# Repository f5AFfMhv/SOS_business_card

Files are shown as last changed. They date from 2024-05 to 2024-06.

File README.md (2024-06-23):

# SOS Business Card PCB

This project was conceived for the [Hackaday 2024 Business Card Contest](https://hackaday.io/contest/195949-2024-business-card-contest). The idea was to create a logical circuit from discrete components that would generate a SOS signal in Morse code. I wanted to make this project a learning experience for creating logical circuits in a simple and practical way.

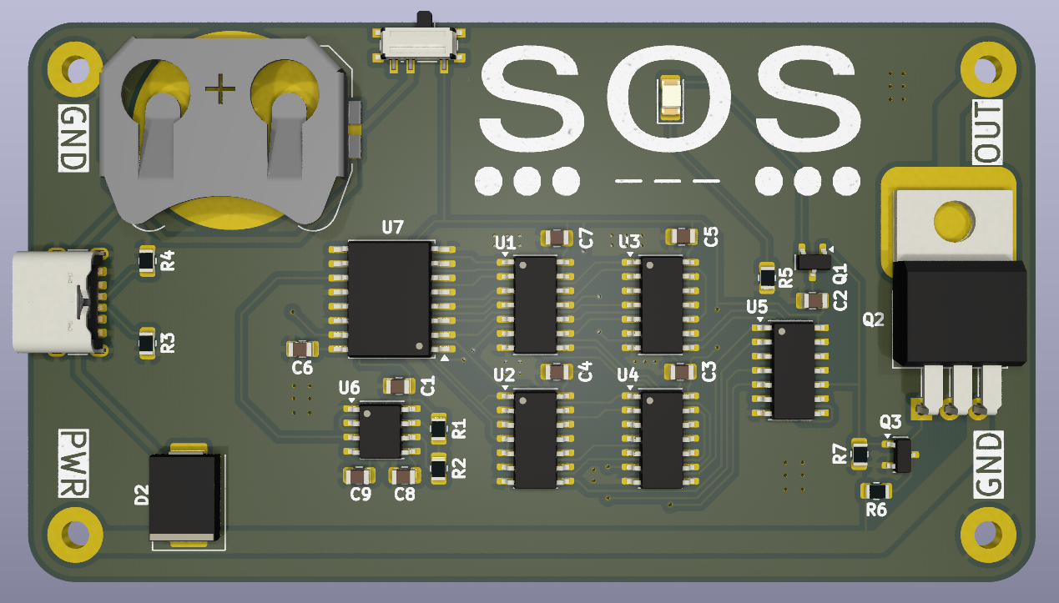
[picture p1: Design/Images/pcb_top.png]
pcb


## Logical Circuit Design

Morse code has following rules for signaling:

- dot is 1 time unit
- dash is 3 time units
- the space between symbols of the same letter is 1 time unit
- the space between words is 7 time units.

Following these rules SOS signal timing diagram will look like this:
wavedrome

> Diagram is made with [wavedrom online tool](https://wavedrom.com/editor.html). You can import json file from `Design/Wavedrom` for modifications.

We see that 34 independent logical states are needed. This introduces a problem as we could reduce logical circuit complexity by using 32 states instead as it will require 5 inputs for our truth table $(2^5=32)$.

I decided to violate last Morse code signaling rule and use 5 time units for spacing between words instead of 7.

I'm using [Logism](http://www.cburch.com/logisim/), it can take truth table as input and generate logical circuit. You can find Logism circuit files in `Design/Logism` directory. Generated circuit is not perfect and can be improved manually (by removing duplicated components and changing number of inputs for logical gates).

<div align="center">
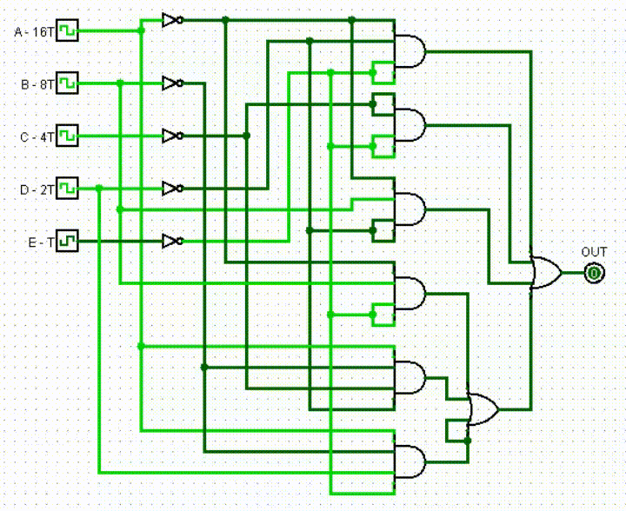
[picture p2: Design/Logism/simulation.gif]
logism
    
</div>

## Clock Circuit Design

For clock signal I'm using 555 timer. There are lots of tools online for calculating 555 timer circuit parameters. I used [555 Astable Circuit Calculator ](https://ohmslawcalculator.com/555-astable-calculator) for this.

General rules are:

- choose R2 value much higher than R1 for 50% duty cycle;
- C9 sets clock frequency. 330nF capacitor will generate 2Hz signal. To increase frequency, decrease C9 value.

<div align="center">
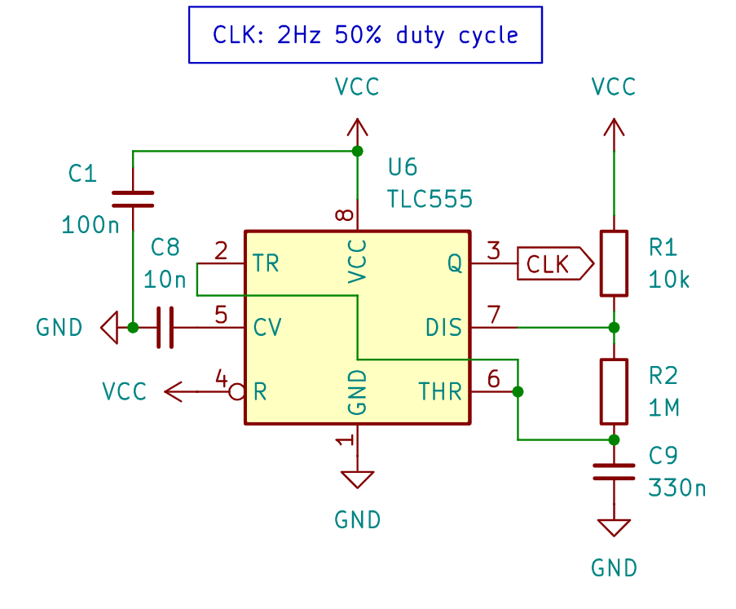
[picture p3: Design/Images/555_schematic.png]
    
</div>

For generating 5-bit logic circuit input signal we'll need binary counter. It will divide clock signal frequency by 2/4/8/16 and so on.

Full circuit simulation with 555 clock generator, binary counter and logical circuit was done using [Falstad](https://tinyurl.com/2bdrotlr). If link doesn't work, you can find Falstad circuit file in `Design/Falstad` directory.

## Power

Circuit will have 2 power options:

- CR2025 coin battery
- USB-C 5V@3A

USB-C socket CC lines are connected to ground via 5.1K ohm resistor. This tells power source to supply 5V on VBUS line. Most ICs I chose have maximum supply voltage of 6V.

## Output

The circuit will have a small on-board LED for SOS signal output. Additionally, a high-side PMOS load switch can be connected to a larger load, such as a 12V lamp. An external power supply with a maximum of 40V will be needed for this.

<div align="center">
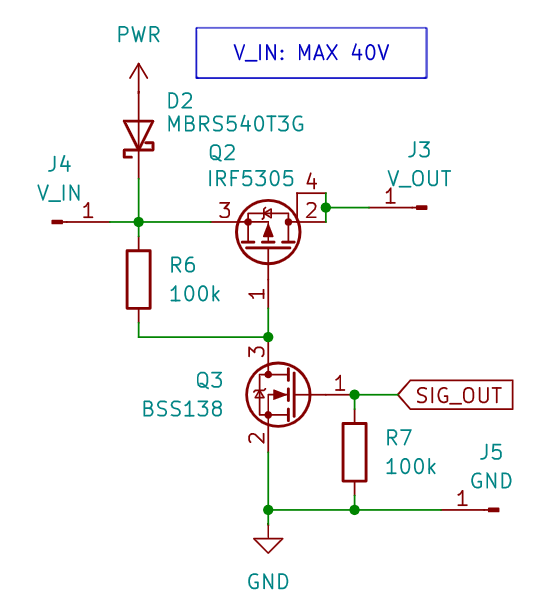
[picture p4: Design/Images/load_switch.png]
load switch
    
</div>

## PCB Design

PCB is designed using KiCAD. All project and gerber files are in `KiCAD` directory.
Full [schematic](schematic.pdf) exported as pdf.

There are some custom symbols and footprints used in this project. Those can be imported from [this](https://github.com/f5AFfMhv/my-kicad-libraries) github repository.

## Finished Project

<div align="center">
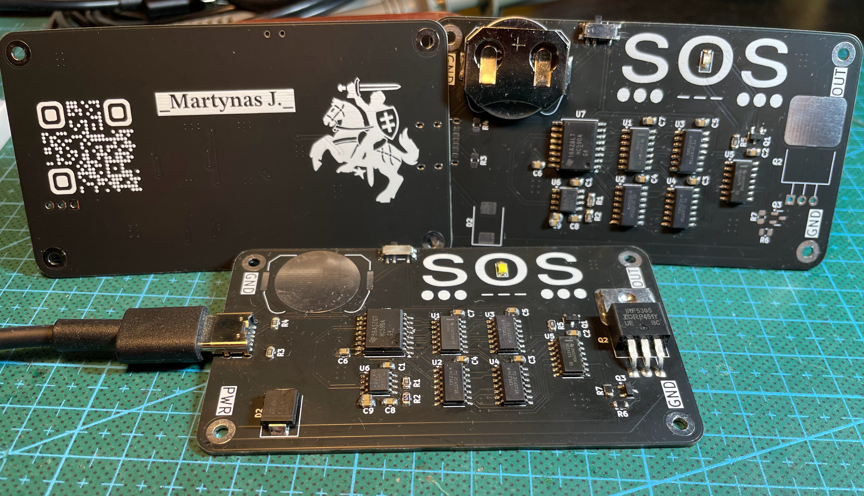
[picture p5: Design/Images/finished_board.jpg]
board
    
</div>

Youtube video.
[](https://www.youtube.com/embed/pKzfa068GOo)

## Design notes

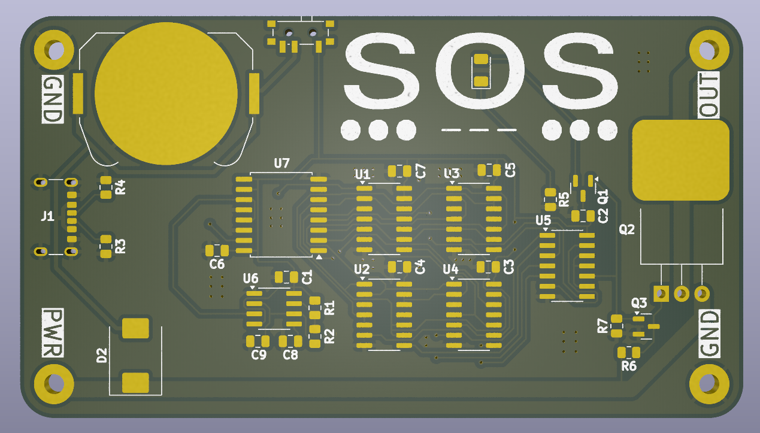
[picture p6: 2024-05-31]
Design/Images/bare_pcb_top.png

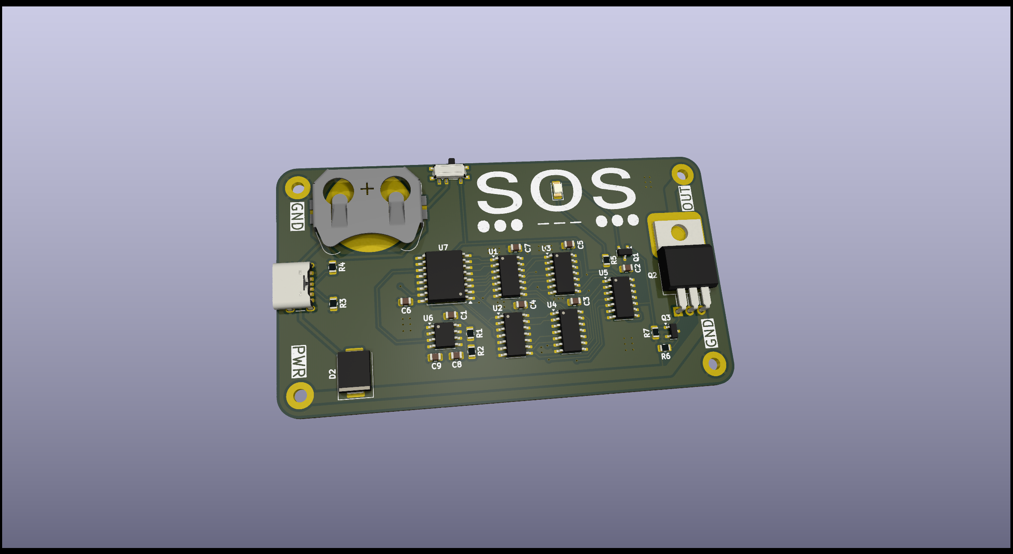
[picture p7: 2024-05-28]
Design/Images/pcb_3d_view_front.png

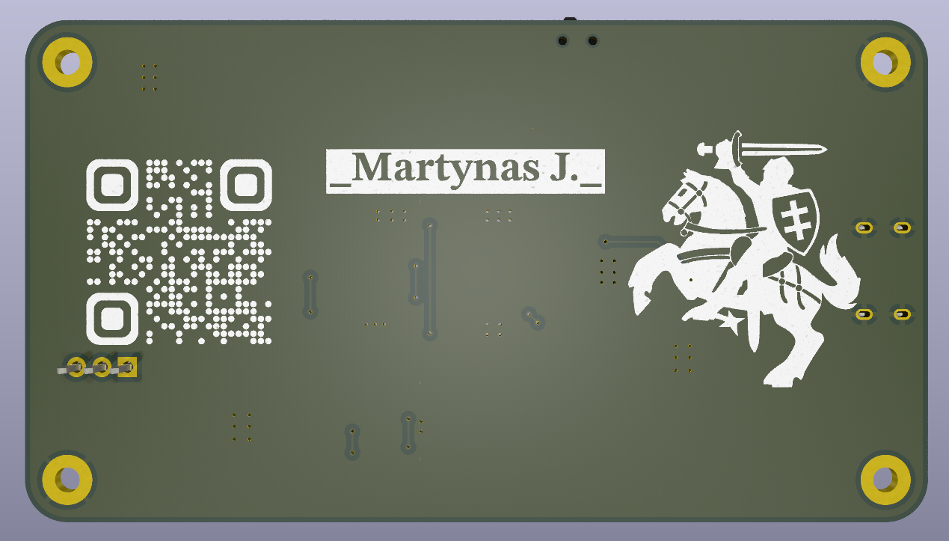
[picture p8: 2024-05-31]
Design/Images/pcb_bottom.png

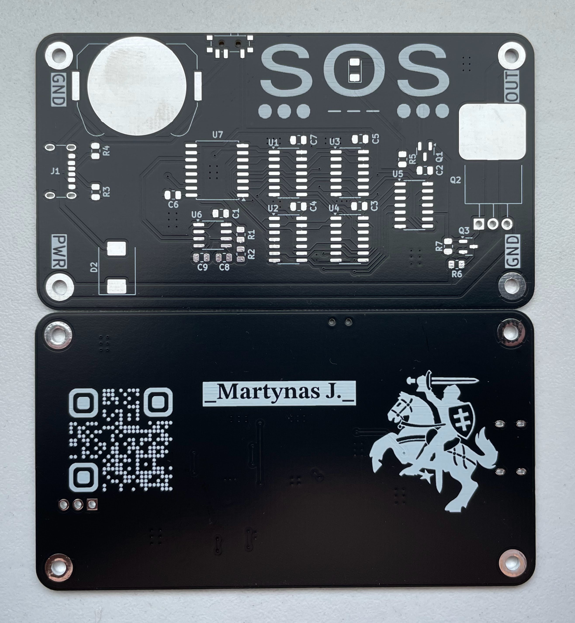
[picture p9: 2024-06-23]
Design/Images/pcb.jpg

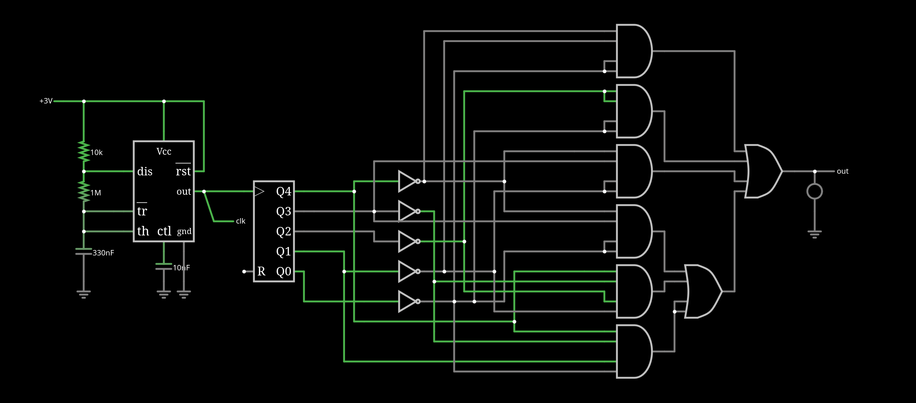
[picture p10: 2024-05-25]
Design/Falstad/falstad.png

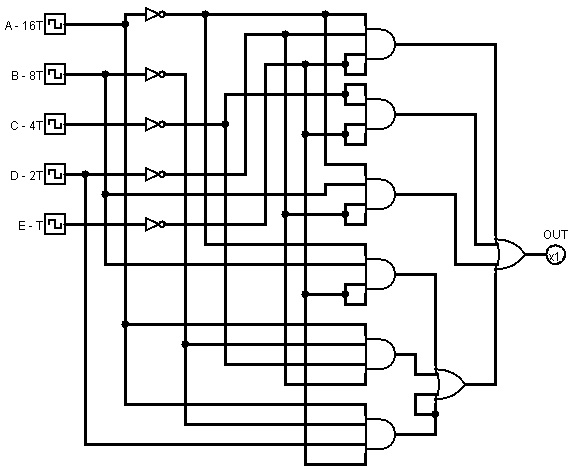
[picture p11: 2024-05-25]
Design/Logism/simplified_circuit.png

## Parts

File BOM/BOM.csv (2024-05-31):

Reference | Value | Datasheet | Footprint | Qty | DNP | Description | Digikey link | Digikey price
BT1 | Battery_Cell | ~ | Battery:BatteryHolder_Keystone_3034_1x20mm | 1 |  | Single-cell battery | https://www.digikey.lt/en/products/detail/keystone-electronics/3034/4499289 | 0.37
C1,C2,C3,C4,C5,C6,C7 | 100n | ~ | Capacitor_SMD:C_0805_2012Metric | 7 |  | Unpolarized capacitor, small symbol |  | 0.1
C8 | 10n | ~ | Capacitor_SMD:C_0805_2012Metric | 1 |  | Unpolarized capacitor, small symbol |  | 0.1
C9 | 330n | ~ | Capacitor_SMD:C_0805_2012Metric | 1 |  | Unpolarized capacitor, small symbol |  | 0.1
D1 | LED | ~ | LED_SMD:LED_1206_3216Metric | 1 |  | Light emitting diode |  | 0.18
D2 | MBRS540T3G | https://www.onsemi.com/pdf/datasheet/mbrs540t3-d.pdf | Diode_SMD:D_SMC | 1 |  | 40V 5A Schottky Barrier Rectifier Diode, SMC | https://www.digikey.lt/en/products/detail/onsemi/MBRS540T3G/918647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 | 0.59
J1 | USB_C_Receptacle_PowerOnly_6P | https://www.usb.org/sites/default/files/documents/usb_type-c.zip | Connector_USB:USB_C_Receptacle_GCT_USB4125-xx-x_6P_TopMnt_Horizontal | 1 |  | USB Power-Only 6P Type-C Receptacle connector | https://www.digikey.lt/en/products/detail/jae-electronics/DX07B024JJ2R1500/5395887 | 1.78
J2,J5 | GND | ~ | MountingHole:MountingHole_2.5mm_Pad_TopBottom | 2 |  | Generic connector, single row, 01x01, script generated
J3 | V_OUT | ~ | MountingHole:MountingHole_2.5mm_Pad_TopBottom | 1 |  | Generic connector, single row, 01x01, script generated
J4 | V_IN | ~ | MountingHole:MountingHole_2.5mm_Pad_TopBottom | 1 |  | Generic connector, single row, 01x01, script generated
Q1,Q3 | BSS138 | https://www.onsemi.com/pub/Collateral/BSS138-D.PDF | Package_TO_SOT_SMD:SOT-23 | 2 |  | 50V Vds, 0.22A Id, N-Channel MOSFET, SOT-23 | https://www.digikey.lt/en/products/detail/evvo/BSS138/22482090 | 0.15
Q2 | IRF5305 | https://www.infineon.com/dgdl/Infineon-IRF5305-DataSheet-v01_01-EN.pdf?fileId=5546d462533600a4015355e370101993 | my:TO-220-3_Horizontal_TabDown_2 | 1 |  | P-MOSFET transistor, gate/drain/source, drain connected to mounting plane | https://www.digikey.lt/en/products/detail/infineon-technologies/IRF5305PBF/811987 | 1.38
R1 | 10k | ~ | Resistor_SMD:R_0805_2012Metric | 1 |  | Resistor |  | 0.1
R2 | 1M | ~ | Resistor_SMD:R_0805_2012Metric | 1 |  | Resistor |  | 0.1
R3,R4 | 5.1k | ~ | Resistor_SMD:R_0805_2012Metric | 2 |  | Resistor |  | 0.1
R5 | 100 | ~ | Resistor_SMD:R_0805_2012Metric | 1 |  | Resistor |  | 0.1
R6,R7 | 100k | ~ | Resistor_SMD:R_0805_2012Metric | 2 |  | Resistor |  | 0.1
SW1 | SW_SPDT | ~ | Button_Switch_SMD:SW_SPDT_PCM12 | 1 |  | Switch, single pole double throw | https://www.digikey.lt/en/products/detail/c-k/PCM12SMTR/1640112 | 1.06
U1 | SN74LV04A | http://www.ti.com/lit/gpn/sn74LV04a | Package_SO:SOIC-14_3.9x8.7mm_P1.27mm | 1 |  | Hex Inverter | https://www.digikey.lt/en/products/detail/texas-instruments/SN74LV04ADR/1590868 | 0.54
U2,U3,U4 | SN74HC21QDRQ1 | https://www.ti.com/lit/ds/symlink/sn74hc21-q1.pdf | Package_SO:SOIC-14_3.9x8.7mm_P1.27mm | 3 |  | Dual 4-input AND | https://www.digikey.lt/en/products/detail/texas-instruments/SN74HC21QDRQ1/1570862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 | 0.59
U5 | SN74HCS4075 | https://www.ti.com/cn/lit/ds/symlink/sn74hcs4075.pdf | Package_SO:SOIC-14_3.9x8.7mm_P1.27mm | 1 |  | Triple Or 3 inputs | https://www.digikey.lt/en/products/detail/texas-instruments/SN74HCS4075DR/12696017 | 0.35
U6 | TLC555 | https://www.ti.com/lit/ds/symlink/tlc555.pdf | Package_SO:SOIC-8_3.9x4.9mm_P1.27mm | 1 |  | Single LinCMOS Timer, 555 compatible, SOIC-8 | https://www.digikey.lt/en/products/detail/texas-instruments/TLC555CDR/276979 | 0.81
U7 | 74HC590A | http://www.ti.com/lit/ds/symlink/sn74hc590a.pdf | Package_SO:SOIC-16W_7.5x10.3mm_P1.27mm | 1 |  | 8-bit Binary Counter with Output Register 3-State Outputs, DIP-16/SOIC-16/SOIC-16W | https://www.digikey.lt/en/products/detail/texas-instruments/SN74HC590ADW/376755 | 0.92

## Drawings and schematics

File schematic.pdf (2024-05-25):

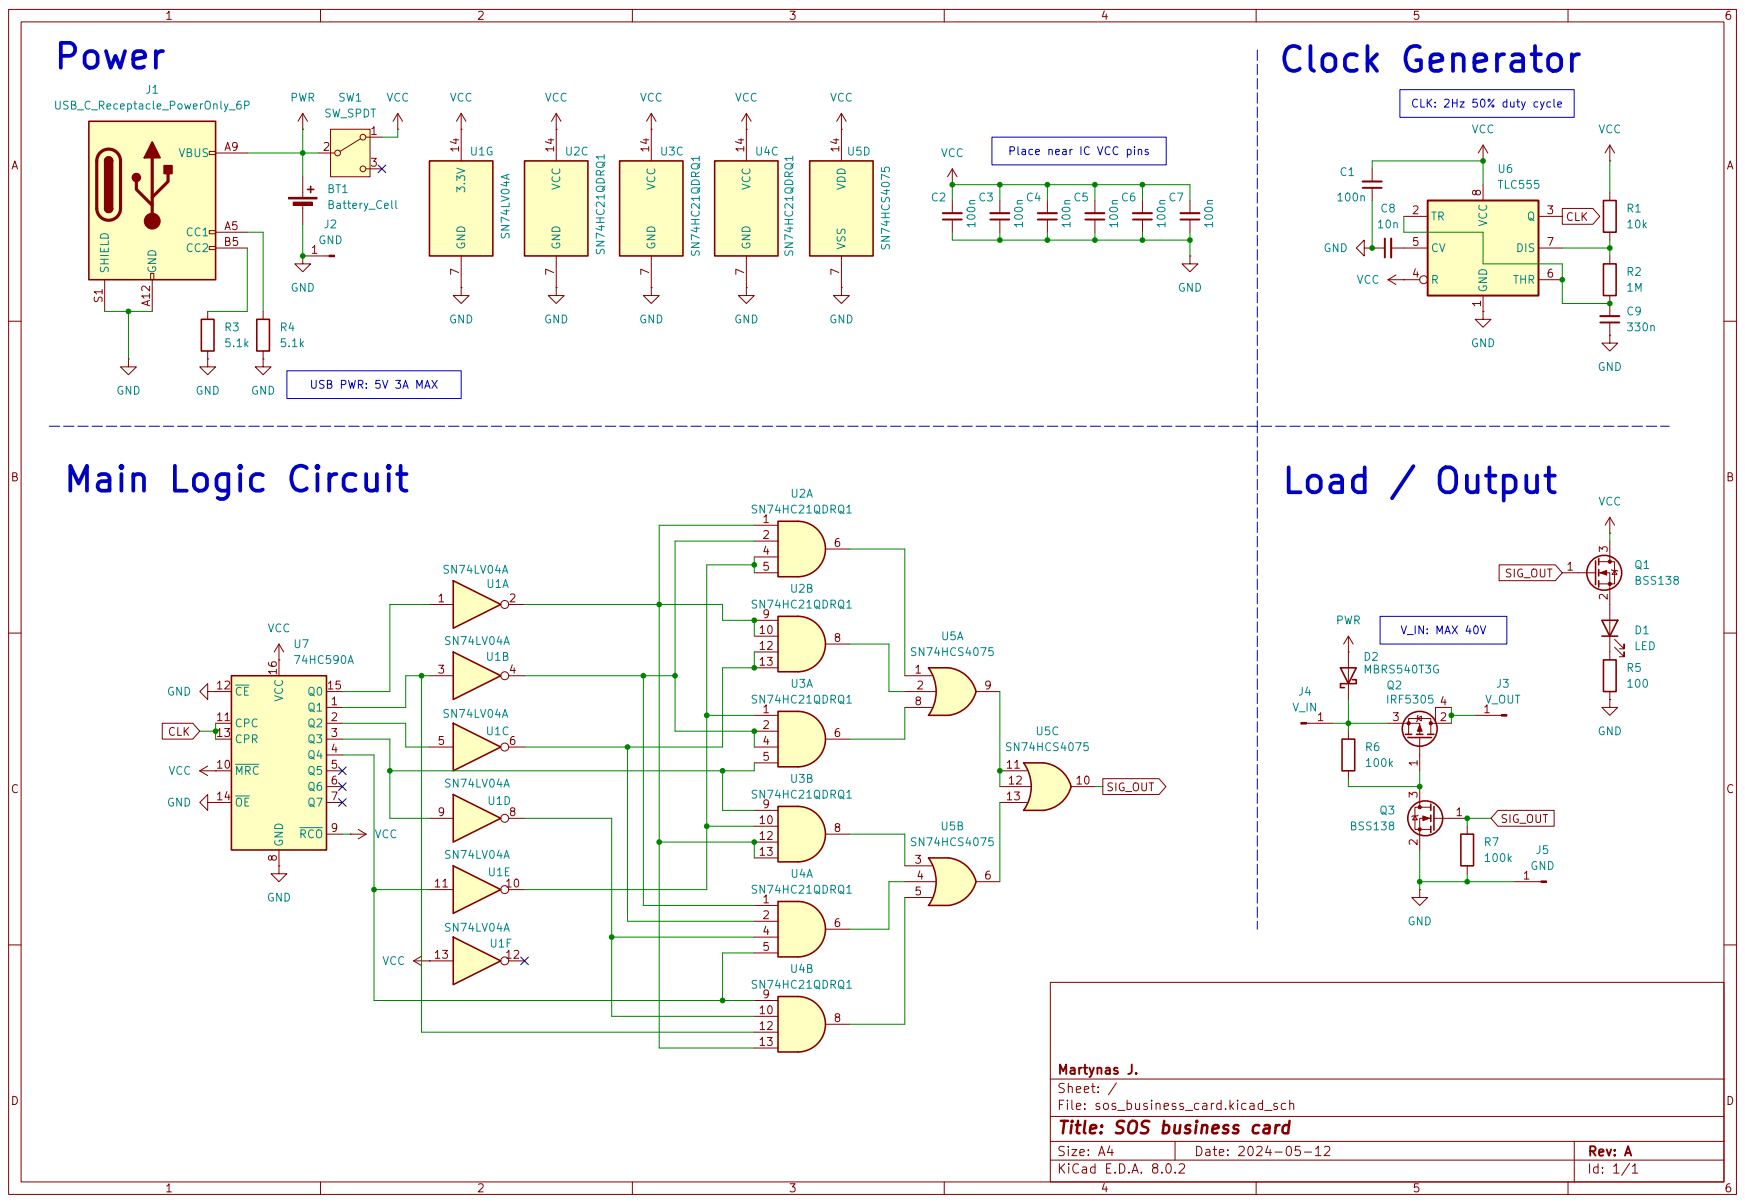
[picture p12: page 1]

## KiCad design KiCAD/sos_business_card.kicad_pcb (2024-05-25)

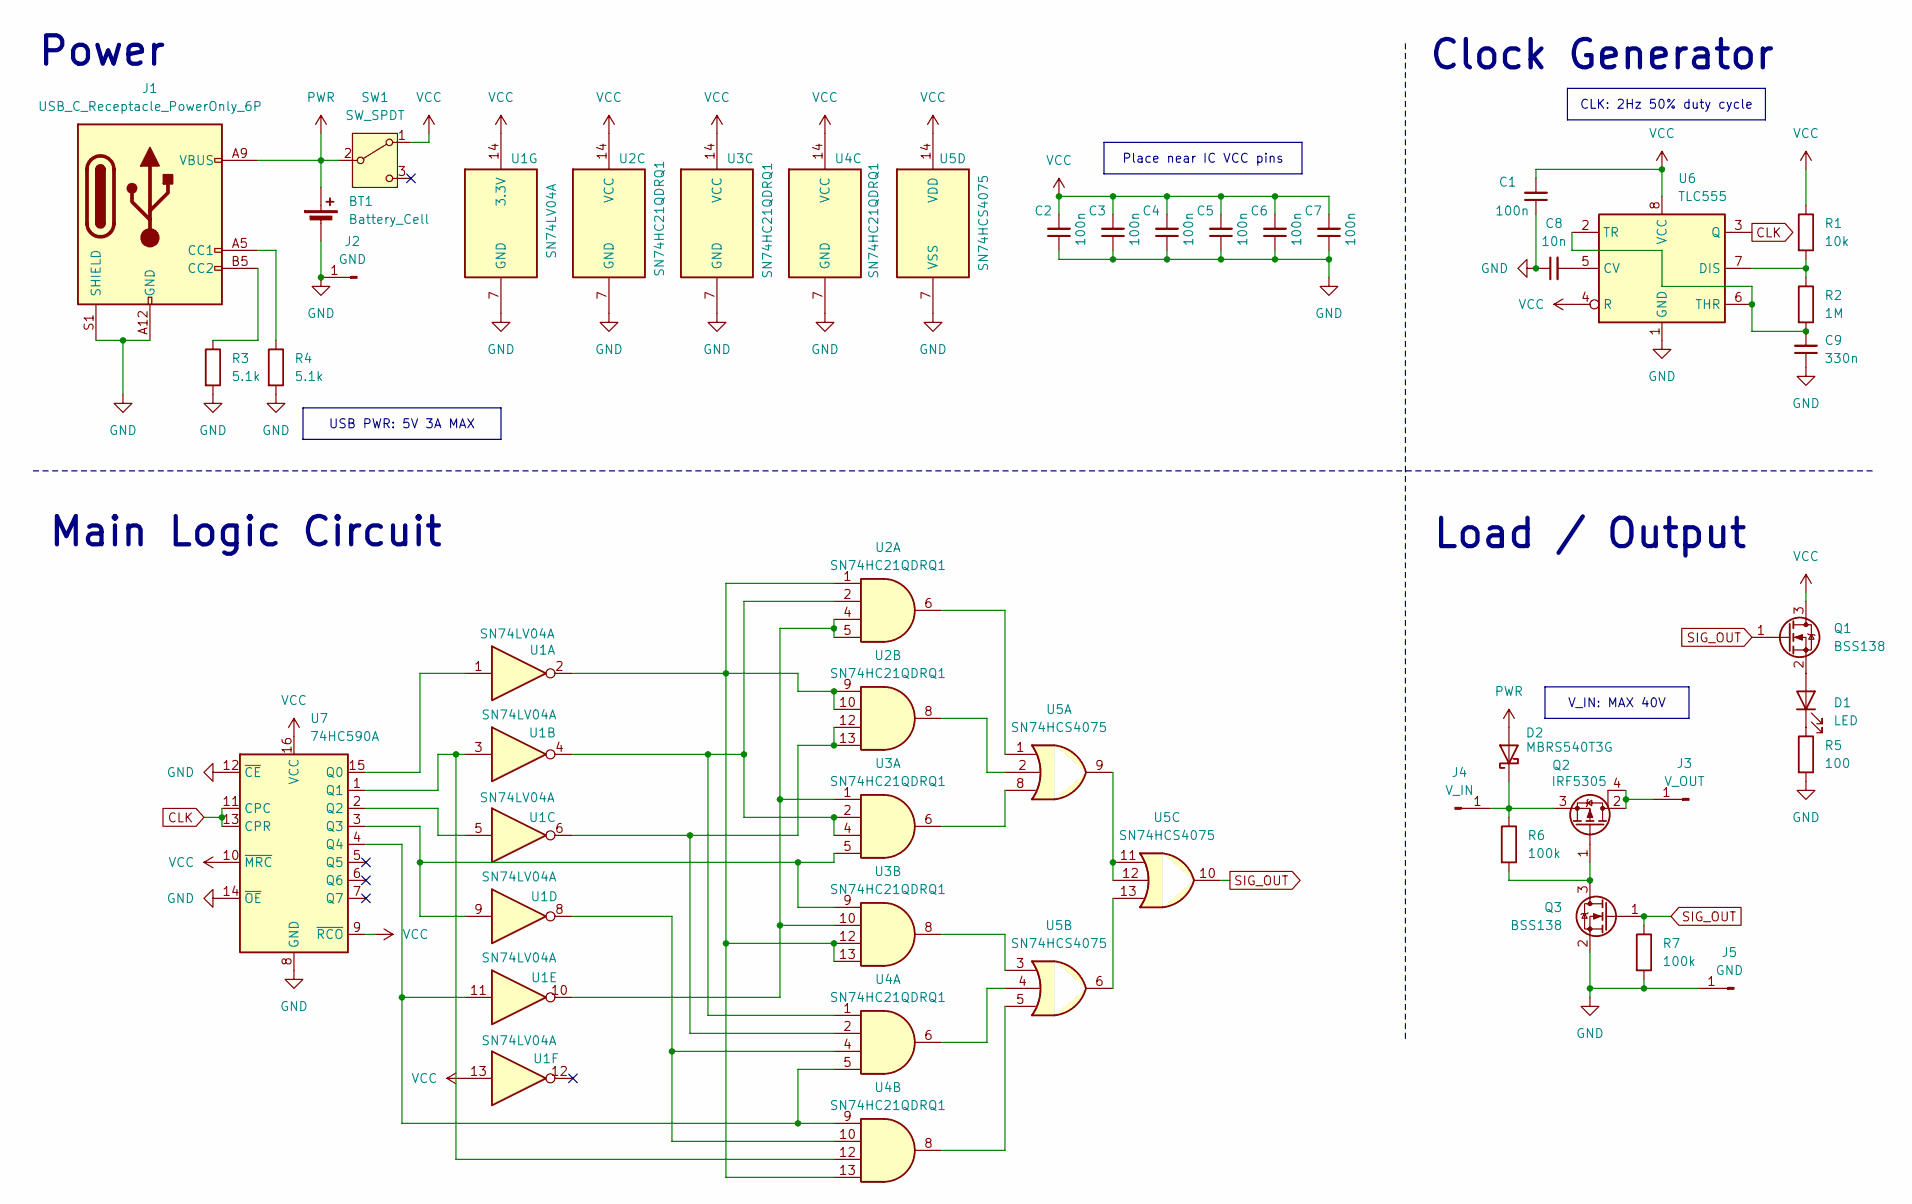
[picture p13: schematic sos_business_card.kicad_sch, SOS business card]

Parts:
BT1: Battery_Cell; BatteryHolder_Keystone_3034_1x20mm
C1, C2, C3, C4, C5, C6, C7: 100n; C_0805_2012Metric
C8: 10n; C_0805_2012Metric
C9: 330n; C_0805_2012Metric
D1: LED; LED_1206_3216Metric
D2: MBRS540T3G; D_SMC
J1: USB_C_Receptacle_PowerOnly_6P; USB_C_Receptacle_GCT_USB4125-xx-x_6P_TopMnt_Horizontal
J2, J5: GND; MountingHole_2.5mm_Pad_TopBottom
J3: V_OUT; MountingHole_2.5mm_Pad_TopBottom
J4: V_IN; MountingHole_2.5mm_Pad_TopBottom
Q1, Q3: BSS138; SOT-23
Q2: IRF5305; TO-220-3_Horizontal_TabDown_2
R1: 10k; R_0805_2012Metric
R2: 1M; R_0805_2012Metric
R3, R4: 5.1k; R_0805_2012Metric
R5: 100; R_0805_2012Metric
R6, R7: 100k; R_0805_2012Metric
SW1: SW_SPDT; SW_SPDT_PCM12
U1: SN74LV04A; SOIC-14_3.9x8.7mm_P1.27mm
U2, U3, U4: SN74HC21QDRQ1; SOIC-14_3.9x8.7mm_P1.27mm
U5: SN74HCS4075; SOIC-14_3.9x8.7mm_P1.27mm
U6: TLC555; SOIC-8_3.9x4.9mm_P1.27mm
U7: 74HC590A; SOIC-16W_7.5x10.3mm_P1.27mm

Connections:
CLK: U6.3 (Q), U7.11 (CPC), U7.13 (CPR)
GND: BT1.2 (-), C1.1, C2.1, C3.1, C4.1, C5.1, C6.1, C7.1, C8.1, C9.1, J1.A12 (GND), J1.B12 (GND), J1.S1 (SHIELD), J2.1, J5.1, Q3.2 (S), R3.2, R4.2, R5.2, R7.2, U1.7 (GND), U2.7 (GND), U3.7 (GND), U4.7 (GND), U5.7 (VSS), U6.1 (GND), U7.8 (GND), U7.12 (~CE), U7.14 (~OE)
unnamed: D1.2 (A), Q1.2 (S)
unnamed: D1.1 (K), R5.1
unnamed: D2.1 (K), J4.1, Q2.3 (S), R6.1
unnamed: J1.A5 (CC1), R4.1
unnamed: J1.B5 (CC2), R3.1
unnamed: J3.1, Q2.2 (D), Q2.4 (D)
unnamed: Q2.1 (G), Q3.3 (D), R6.2
unnamed: U1.2, U2.1, U2.9, U2.10, U3.12, U3.13, U4.13
unnamed: U1.4, U2.2, U3.2, U3.4, U4.1
unnamed: U1.6, U2.12, U2.13, U4.2
unnamed: U1.8, U4.4, U4.10
unnamed: U1.10, U2.4, U2.5, U3.1, U3.10
unnamed: U2.6, U5.1
unnamed: U2.8, U5.2
unnamed: U3.6, U5.8
unnamed: U3.8, U5.3
unnamed: U4.6, U5.4
unnamed: U4.8, U5.5
unnamed: U5.9, U5.11, U5.12
unnamed: U5.6, U5.13
unnamed: C8.2, U6.5 (CV)
unnamed: R1.2, R2.1, U6.7 (DIS)
unnamed: C9.2, R2.2, U6.2 (TR), U6.6 (THR)
unnamed: U1.1, U7.15 (Q0)
unnamed: U1.3, U4.12, U7.1 (Q1)
unnamed: U1.5, U7.2 (Q2)
unnamed: U1.9, U3.5, U3.9, U7.3 (Q3)
unnamed: U1.11, U4.5, U4.9, U7.4 (Q4)
PWR: BT1.1 (+), D2.2 (A), J1.A9 (VBUS), J1.B9 (VBUS), SW1.2 (B)
SIG_OUT: Q1.1 (G), Q3.1 (G), R7.1, U5.10
VCC: C1.2, C2.2, C3.2, C4.2, C5.2, C6.2, C7.2, Q1.3 (D), R1.1, SW1.1 (A), U1.13, U1.14 (3.3V), U2.14 (VCC), U3.14 (VCC), U4.14 (VCC), U5.14 (VDD), U6.4 (R), U6.8 (VCC), U7.9 (~RCO), U7.10 (~MRC), U7.16 (VCC)

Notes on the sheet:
V_IN: MAX 40V
CLK: 2Hz 50% duty cycle
Place near IC VCC pins
USB PWR: 5V 3A MAX
Main Logic Circuit
Clock Generator
Power
Load / Output

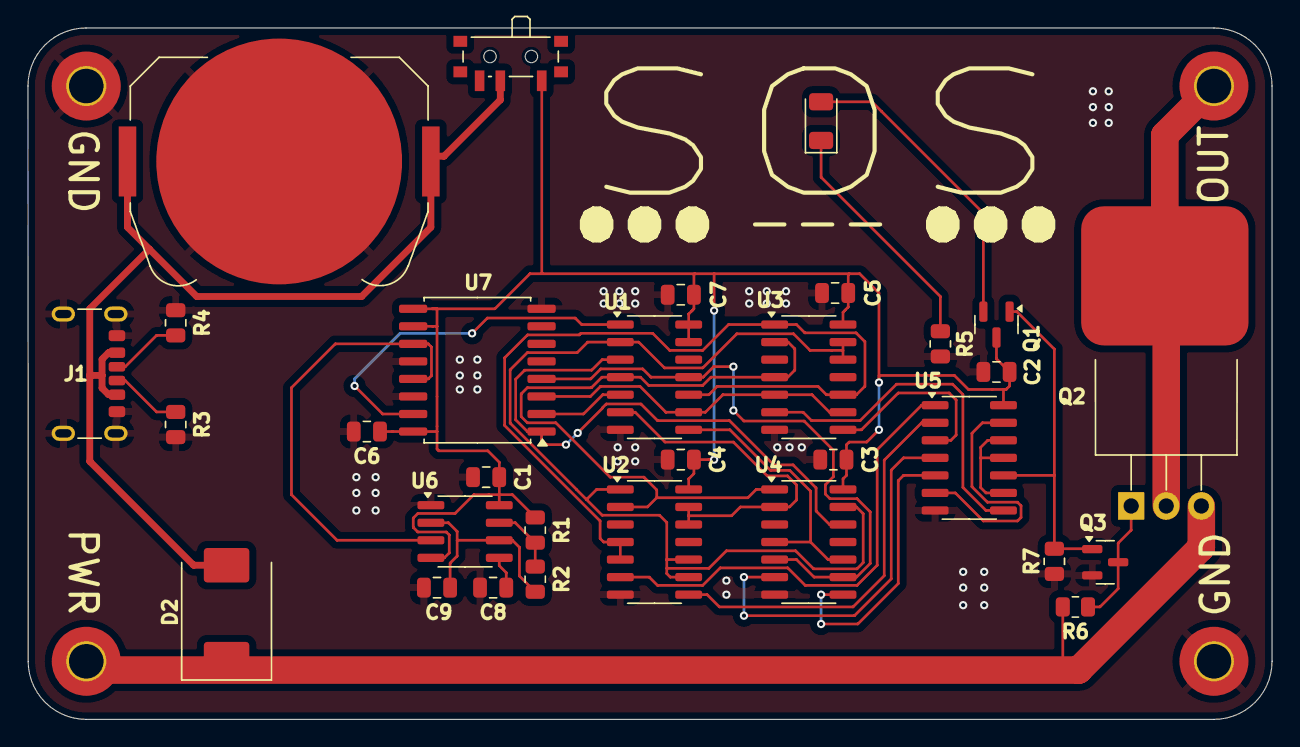
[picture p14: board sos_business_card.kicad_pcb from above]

Board: 2 copper layers, 90.1 x 50.1 mm, 35 parts (0 on the bottom side), 33 nets.
